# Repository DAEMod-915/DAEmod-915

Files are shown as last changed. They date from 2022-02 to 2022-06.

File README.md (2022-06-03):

# DAEMod-915
Bradley University senior capstone project by Peter Handler, Connor Dickey, and Philip Pierce for a 915MHz ISM open-source and open-hardware digital transceiver implementing Digital radio modes that uses a configurable duty cycle compared to the proprietary alternative LoRa. The goal is to create an example board for digital radio communication. Our design focuses on extensible and easy communication which is configurable to specific use cases like a remote trail camera system or a modernized pager system. We chose low-cost and ubiquitous hardware to build a sustainable platform. Overall, this repository showcases the potential use cases of a finalized product

For more information please read all the existing [documentation](./docs/) about the project.

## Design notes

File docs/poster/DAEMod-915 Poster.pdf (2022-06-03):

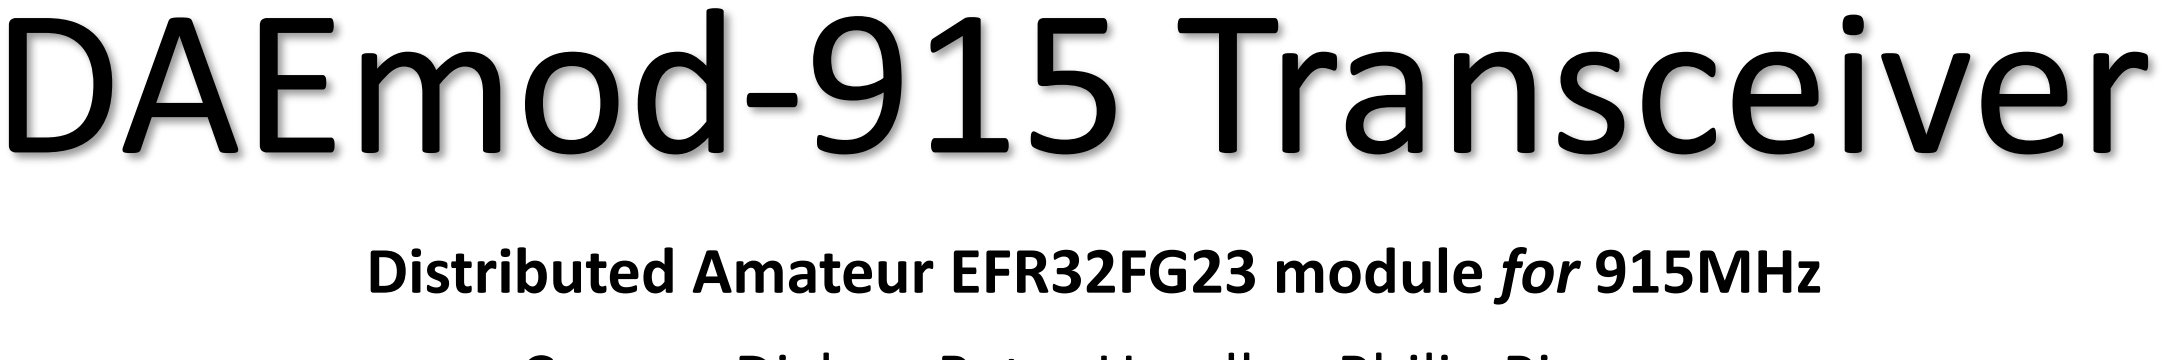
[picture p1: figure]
DAEmod-915 Transceiver

# Distributed Amateur EFR32FG23 module for 915MHz Connor Dickey, Peter Handler, Philip Pierce Advisors: Dr. Prasad Shastry and Dr. Aleksander Malinowski

### Bradley University Department of Electrical and Computer Engineering

# Goals

We are creating a 915MHz open-source and open-hardware system for digital radio experimentation in the under-utilized 915MHz ISM band allocation. The main features of the project include a configurable duty cycle and support for multiple FSK/ASK modes. As a result, it is configurable to specific use cases like a remote trail camera or a modernized pager system. We chose low-cost and ubiquitous hardware (ESP32, I2C sensors, EFR32FG23, ...) to build a sustainable platform and showcase the potential use cases of a finalized product. Overall, our design focuses on extensible and easy communication where traditional infrastructure is not suitable.

# Abstract

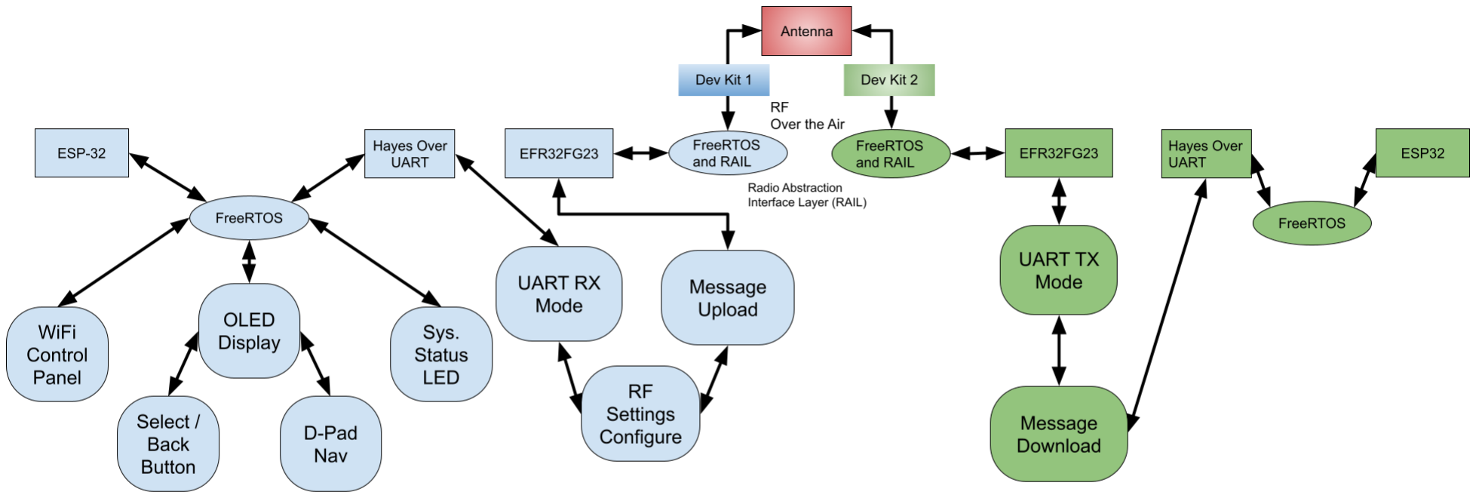
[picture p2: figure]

## ESP32

- Development environment in PlatformIO for VSCode using Espressif 32.
- ESP-PROG for live debugging
- Create set of control signals over UART in the form of AT / Hayes commands.
- Listen on local WiFi server with options to send and print received data.
- GPIO button to start web server, automatically sleep after inactivity.

In the US, the 915MHz band is one of the Industrial, Scientific, and Medical bands that covers a frequency range of 902–928 MHz. Besides LoRa, this band isn't as widely used as 433MHz or 2.4GHz. In the table, we compare our goal product against LoRa

# Background Info

The prototype for the DAEmod-915 is basic PCB design for the development and single board device for use in the DAEmod-915 ecosystem. While the board prototype has not yet gone to production, the board will be produced in a small run to test before the first batch of boards is placed.

# Prototype

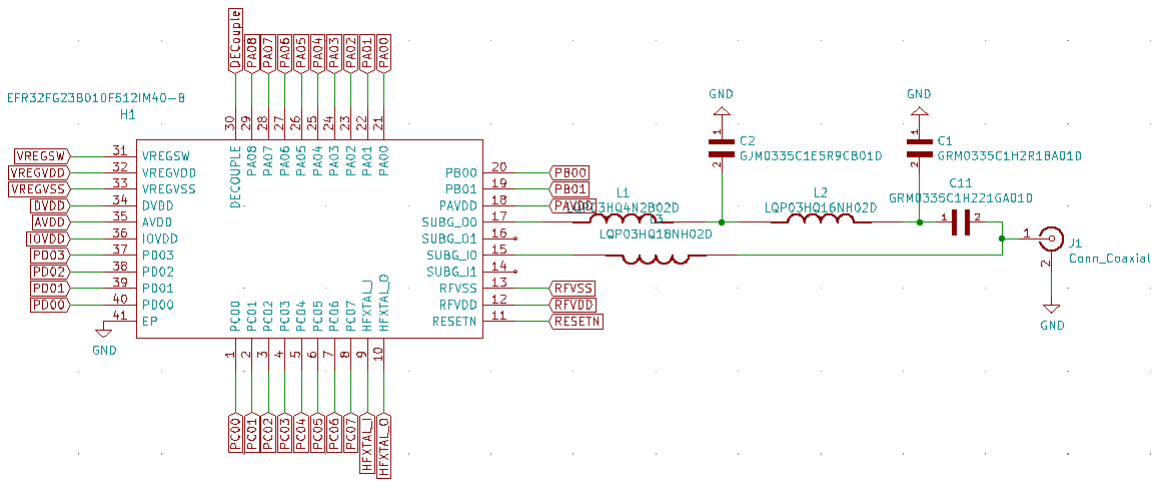
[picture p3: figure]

# Testing Procedures

PCB: The prototype PCB design is at the beginning stages while we wait for parts from the first round grant from the ARDC. The prototype PCB will include mounting locations for the OLED screen, battery connector, GPIO pins, dev kit EFR32FG23, and ESP32 headers. This PCB is a interconnect and tinker board for the project. With room for intergraded modules and future hardware that will be designed for specific products and use cases.

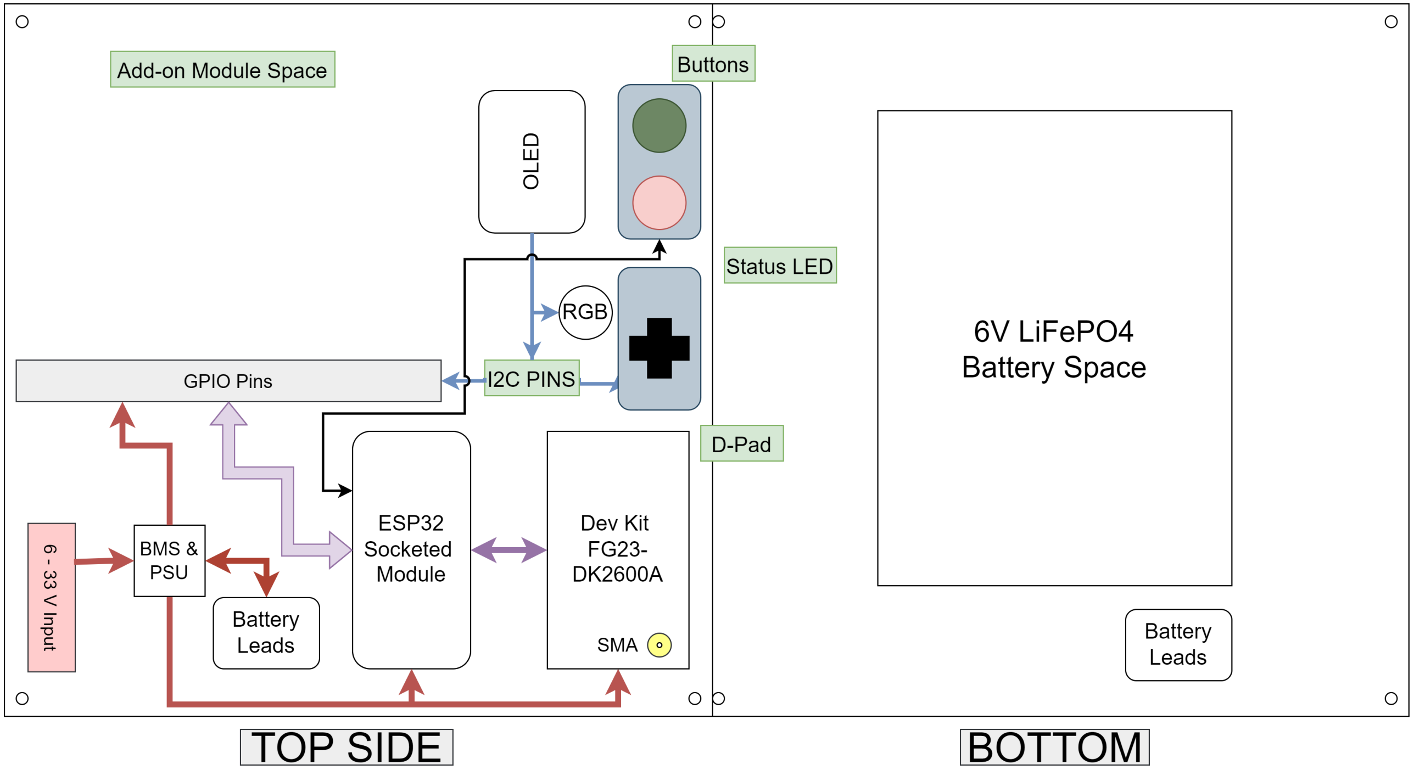
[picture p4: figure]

GitHub: Continued development thought the project GitHub will allow for third-party contributors to continue and expand the software and hardware support. This support will allow for new hardware to be compatible with the current hardware and future hardware. The GitHub will also host documentation for new data modes to be supported by the hardware which can change the use case for the hardware.

Funding: Once the prototype stage of the project is completed, a new grant for a limited production run will be requested from ARDC (Amateur Radio Digital Communications). This grant will allow for development kits for the post-prototype version of the board to be created and seeded for continued development and testing by amateur radio operators and developers.

# Future Development

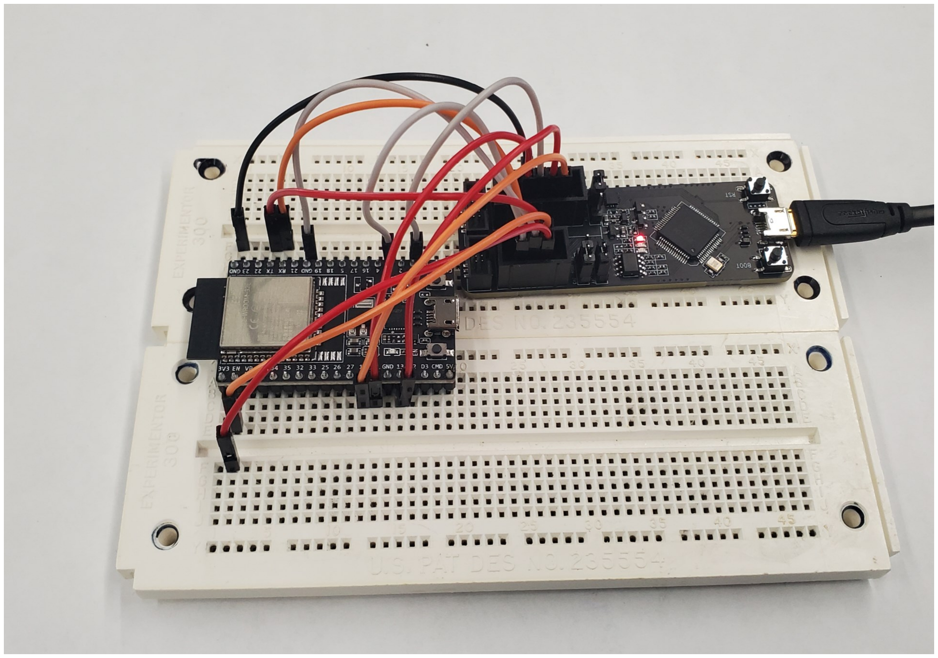
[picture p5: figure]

## Dev Kit FG23-DK2600A

- Development environment in Simplicity Studio
- Low Cost, $40
- Selectable modulation schemes including: FSK, ASK, GFSK, AFSK, GMSK, OOK, OQPSK-DSSS
- Silicon Labs IC for final PCB EFR32FG23A010f256GM48
| LoRa | Our Product
Frequency | 902-928 MHz | 902-928 MHz
Data Rate | 300 bit/s -27 kbit/s | 512 bit/s -400 kbit/s
Duty Cycle | Very Low | Up to 100%
Hand-Shake | Required Handshake | Optional Handshake
Broadcasting | Does not Support | Support
License | $6000 Yearly | GPLv3

The prototype of this project is designed to allow developers and enthusiasts to attach various modules with additional functionality using various Communication I/O Protocols, We are planning to roll out our initial proof-of-concept with Display, GPS, Battery, and Environment Sensors. The display allows users to see system status and information at a glance and the Battery will allow for portable use. Module support will not stop there, as the ability to continue development with future devices is likely with the massive catalog of common products that use UART, SPI, I²
C. As an example, we can imagine advanced sensors like Doppler Radar or Thermal Imaging sensors being useful to examine the state of real world objects without infrastructure.

# Prototype Block Diagram

# Software Design

## •Adhere to open source software and hardware design philosophy •Build a modular and low cost prototype allowing entire community

to contribute.

## •Create highly configurable firmware which is easily modifiable by

community and end users.

Our quantitative testing will be done with the Battery, ESP, Display, RGB LED, and Transceiver.
- Max Range Testing for 2dbi and 5dbi Antenna
- Theoretical 1.80 Miles for 2dbi
- Theoretical 9.3 Miles for 5dbi
- Power Draw on Maximum RF Tx Power
- Power Draw on Minimum RF Tx Power
- Data Rate at max range for different RF Protocols
- Spurious emissions
- Power envelop of signal
- Signal to Noise Ratio

Our function testing outline to validate the proof-of-concept system.
- Component level testing
- Software stability
- Proper hardware connections
- Transceiver Module Operation
- Successful Tx/Rx modulation
- Compliance with regulations
- Module Testing
- Operates as intended
- Communication between systems

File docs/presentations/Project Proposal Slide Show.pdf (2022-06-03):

# 915 MHz Transceiver for Digital Communication

Team: Peter Handler, Philip Pierce, and Connor Dickey
Advisors: Dr. Aleksander Malinowski and Dr. Prasad Shastry Department of Electrical and Computer Engineering, Bradley University

Presentation Outline ● Why this project exists ● Device Specifications ● System Modularity ● Project Timeline ● Additional Considerations ● Conclusion

# Why this project exists

# Project overview

### - Lack of available 915MHz open-source and open-hardware modules - As an example use case and practical implementation of the 915MHz module - Enable extensible and easy communication tailored to more specific use cases

- Low Cost and ubiquitous hardware to facilitate inexpensive modules.

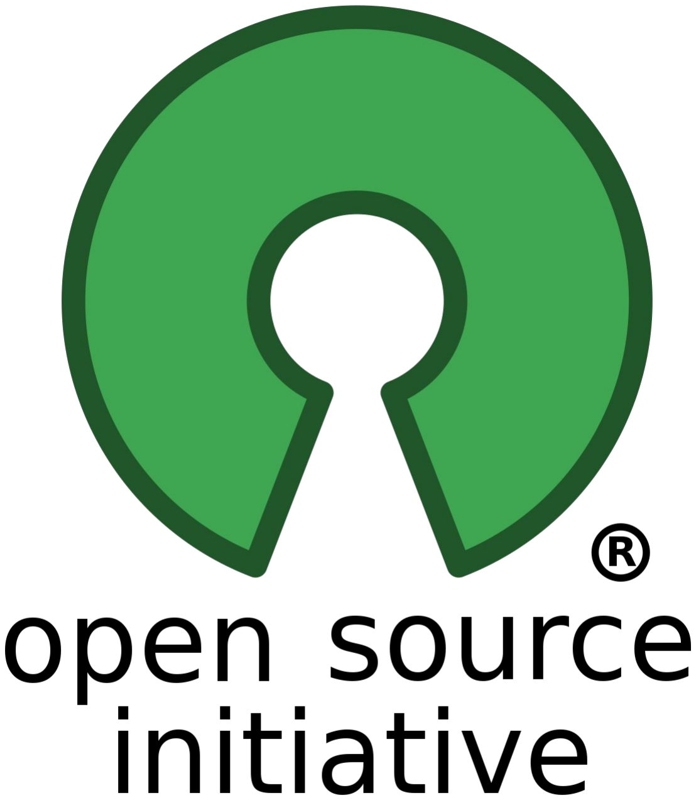
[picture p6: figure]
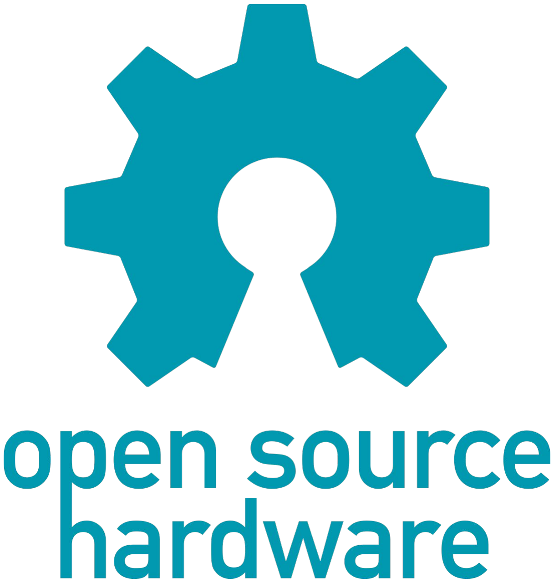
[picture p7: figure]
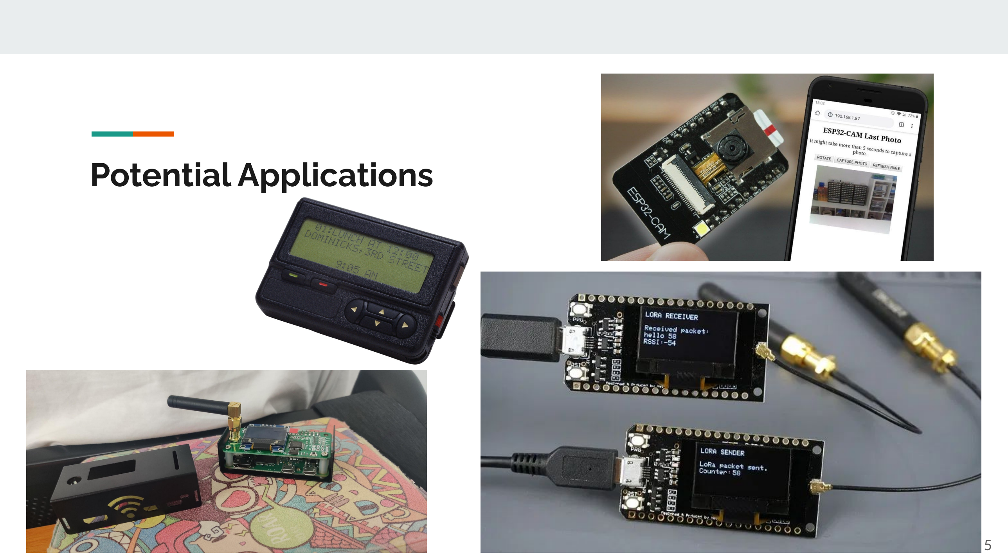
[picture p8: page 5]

# Potential Applications

# Table of LoRa WAN vs our Product

| LoRa | Our Product
Frequency | 902-928 MHz | 902-928 MHz
Data Rate | 300 bit/s - 27 kbit/s | 512 bit/s - 9.6 kbit/s
Duty Cycle | Very Low | Up to 100%
Hand-Shake | Required Handshake | Optional Handshake
Broadcasting | Does not Support | Support
License | $6000 Yearly | Free for use

# Device Specifications

# Preliminary Specifications of Transceiver module

- Theoretical Range
- 2dbi Antenna ideal range is 2.9km (1.80 Miles)
- 5dbi Antenna ideal range is 15km (9.3 Miles)
- Baseline Current draw at 3.3V
- Sleep draw is .8mA
- Full TX draw is 120mA
- RX draw is 20mA
Transceiver | MAX 7037
Modulation | FSK ASK
Antenna | SMA male 50 Ω
Power Max | 10 dBm - 10mW
Frequencies | 915 ISM band (902-928 MHz)

# Preliminary Specifications of Control module

- Baseline Current draw 3.3V
- Sleep draw is .8mA
- RF Tx off draw is 40mA
- RF Tx on draw is 160mA
- RF Tx off, Wifi/BT on draw 240mA
- External power budget 12V
- 1A peak draw to peripheral devices
Microcontroller | ESP 32
Communication I/O Protocols | SPI, I2C, WiFi, BT UART
Power Supply | 12V → 5V → 3.3V
Supported Modules | Camera, Display, GPS, Battery, and Environment Sensor

Function testing | Quantitative Testing
- Component level testing
- Software stability
- Proper hardware installation
- Digital Radio
- Successful Tx/Rx modulation
- Compliance with regulations
- Module Testing
- Operates as intended
- Communication between systems
- Max Range Testing for 2dbi Antenna
- Max Range Testing for 5dbi Antenna
- Power Draw on Maximum RF Tx Power
- Power Draw on Minimum RF Tx Power
- Power Draw for different RF Protocols

B.O.M.

QTY | Vendor | Vendor Part | ITEM DESCRIPTION | UNIT PRICE | TOTAL
1 | Digikey | MAX7037EVKIT915#-ND | Eval Board Max7037 | $254.99 | $254.99
10 | Digikey | MAX7037EGL+-ND | MAX7037 Chips | $5.96 | $59.62
2 | Digikey | 343-ANT-916-CW-RCL-SMA-ND | SMA 900Mhz Hi Gain (Small) Antenna | $8.68 | $17.36
2 | Digikey | 2151-RST-W1B6-10808-22M-FY-001-ND | SMA 900Mhz Low Gain (Small) Antenna | $4.64 | $9.28
2 | Digikey | 1597-104020250-ND | OLED Display 1.12 (SH1107) v3.0 128x128 resolution | $12.50 | $25.00
1 | Digikey | 1597-103020272-ND | I2C HUB (6 PORT) | $1.70 | $1.70
1 | Digikey | 1597-1092-ND | 4PIN MALE JUMPERS 5PACK | $3.20 | $3.20
1 | Digikey | 1597-109020022-ND | GPS module for GPS / Beidou / Glonass / Galileo / QZSS / SBAS | $13.10 | $13.10
2 | Digikey | 1597-1674-ND | Switch Human Interface 5WAY | $4.90 | $9.80
2 | Digikey | 1597-104020169-ND | RGB LED | $4.40 | $8.80
2 | Digikey | 1597-111020103-ND | Switch Human Interface Large Dual Button | $2.40 | $4.80
1 | Digikey | 223-1785-ND | MS8607 SENSOR FOR GROVE SYSTEM | $16.09 | $16.09
2 | Digikey | 1597-1687-ND | ESP32-CAM 2MP WIFI+BT AI-THINKER | $10.00 | $20.00
2 | Digikey | 1965-ESP32-DEVKITC-32E-ND | ESP32-WROOM-32E series Transceiver Evaluation Board | $10.00 | $20.00
1 | Amazon | SMA Female Base | SMA Female Jack Connector 10-Count | $7.89 | $7.89
1 | Amazon | B07BBPX8B8 | UART Cable | $10.99 | $10.99
SUBTOTAL | $482.62
SHIPPING | $12.00
TOTAL | $494.62

# System Modularity

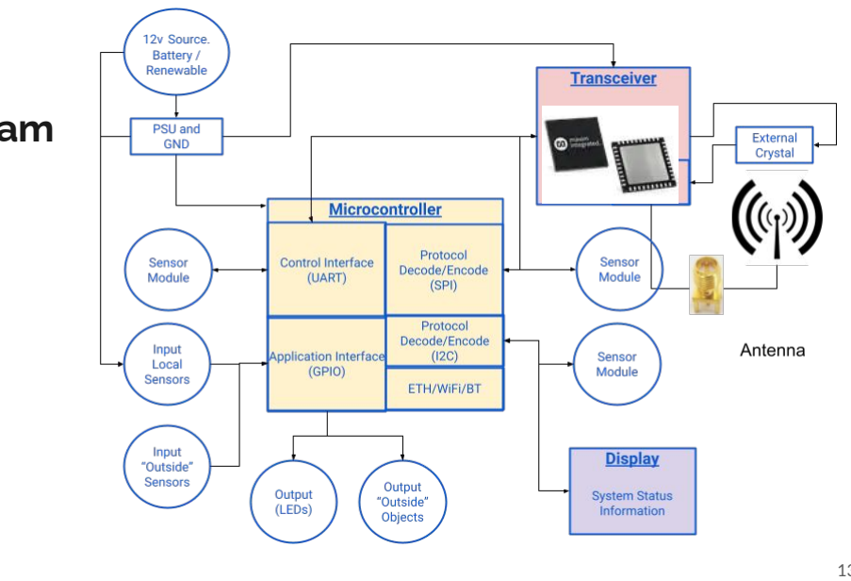
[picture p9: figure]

# Block Diagram

# Potential Modular Accessory

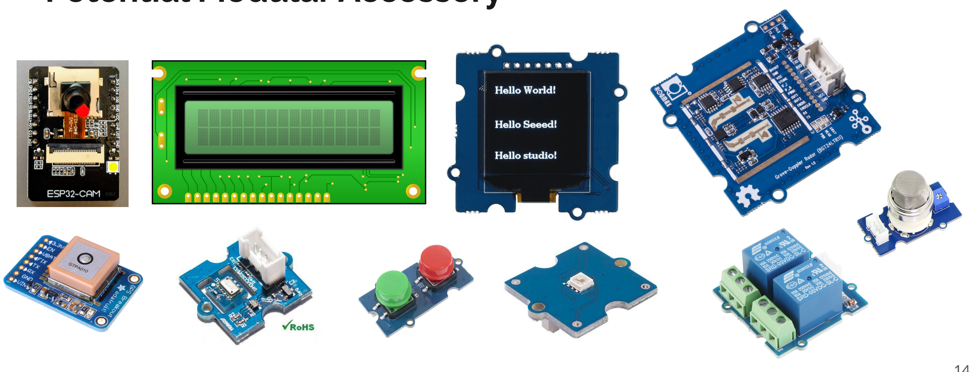
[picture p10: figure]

# Project Timeline

# High Level Timeline Overview

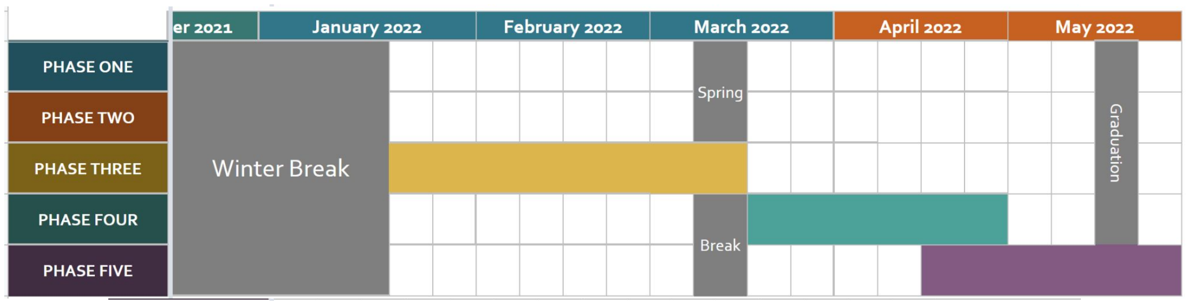
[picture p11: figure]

Senior Project Progress

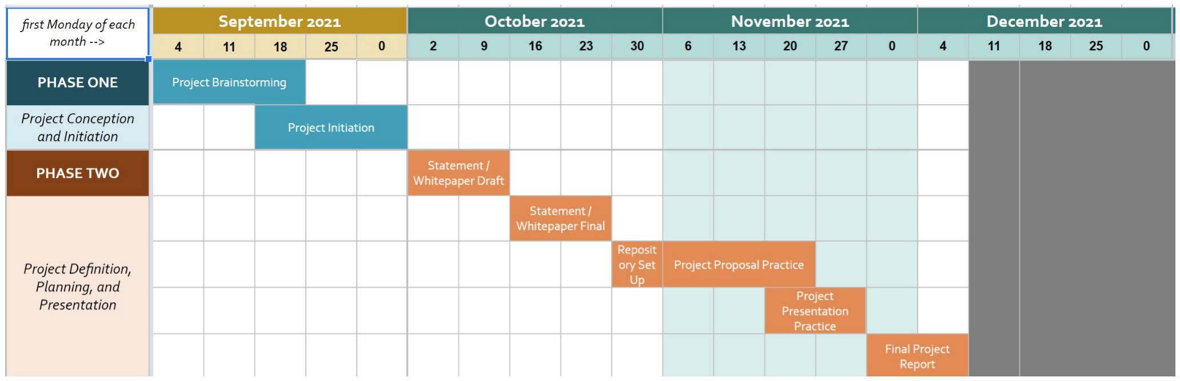
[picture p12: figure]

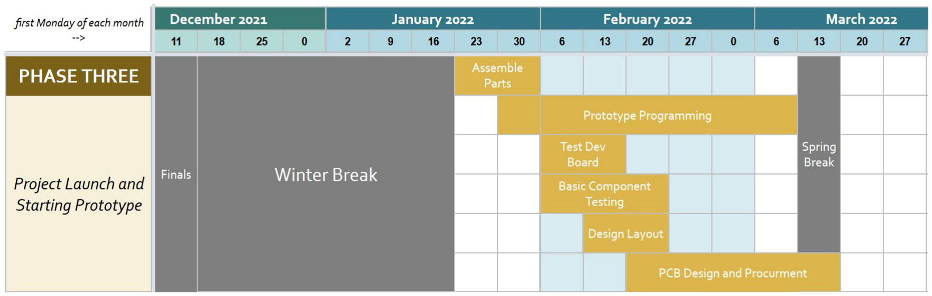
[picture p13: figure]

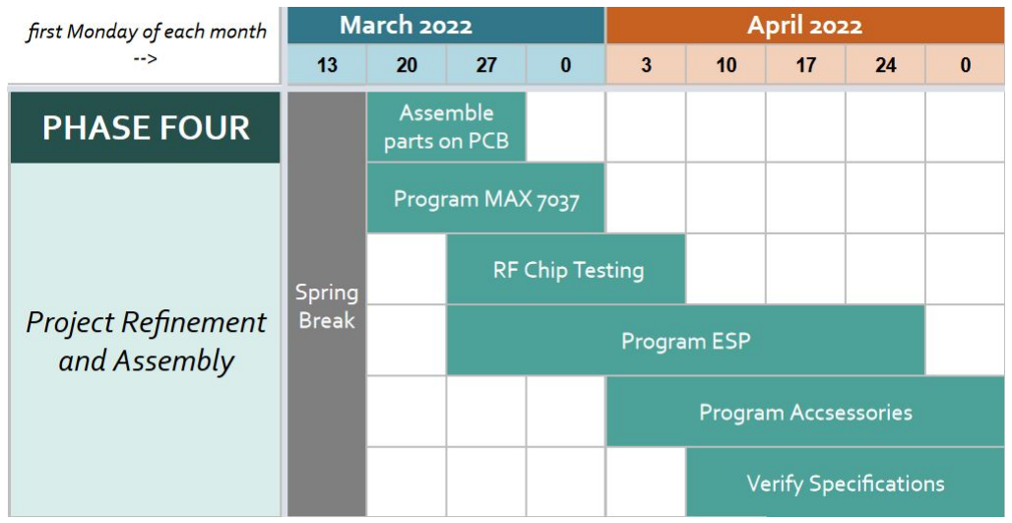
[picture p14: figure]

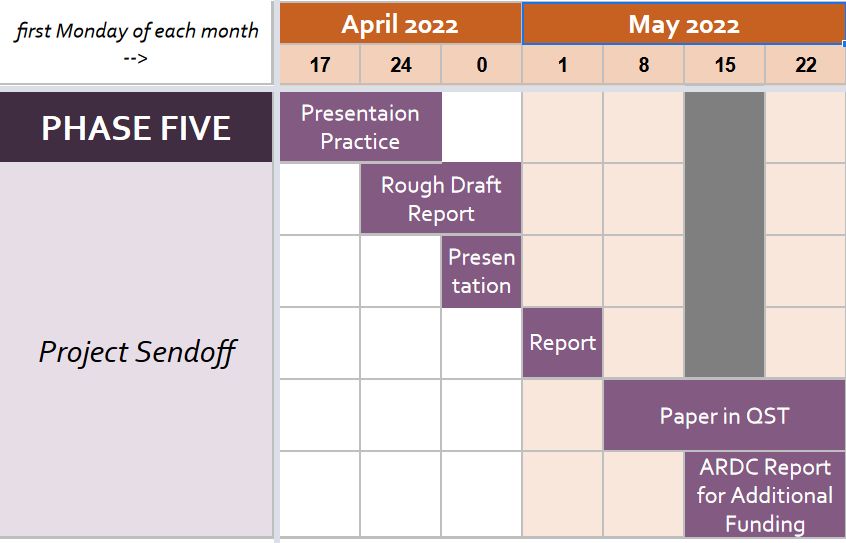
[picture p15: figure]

# Division of Work

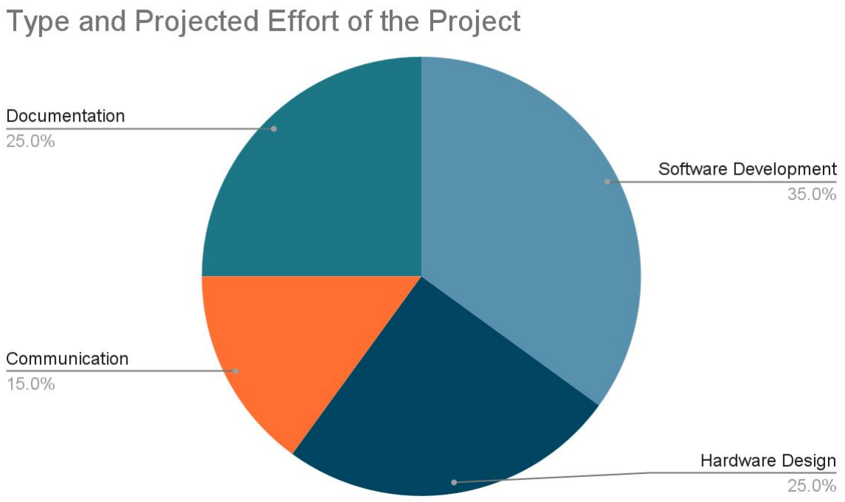
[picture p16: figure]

- Software Development
- Hardware Design
- Communication Schemes
- Documentation
- All have general knowledge in topics

# Parts

Three rounds of funding

1. ECE Department
2. ARDC R&D
3. ARDC Production

# Additional Considerations

Software and Tools ● PCB Designer / CAD ○ -Keysight PathWave ADS ○ -KiCAD ● Embedded Systems Development ○ VS Code + ESP-IDF ESP32 ○ Github ● RF Lab ○ Network Analyzer ○ Spectrum Analyzer ○ Oscilloscope ○ Logic Analyzer

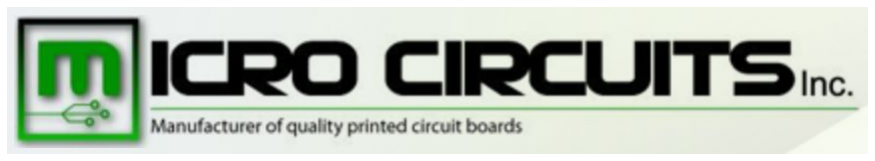
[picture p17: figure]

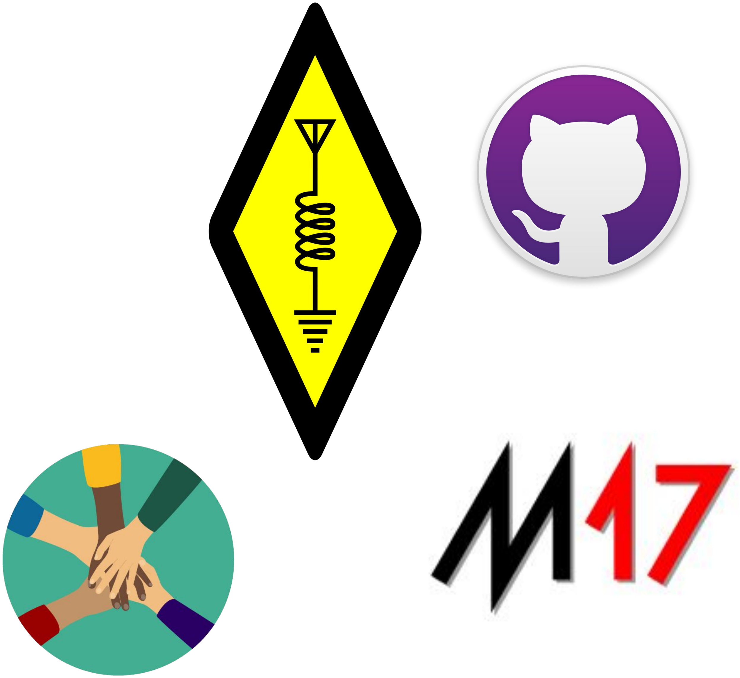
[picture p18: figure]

# Project Future

### - Endless Applications - Driven by Community Engagement - Additional Communication Protocols

# Conclusion

# In Summary

### - Microcontroller powered RF transceiver board for digital radio modes in the

915 MHz ISM band.

### - Will be entirely Open source and Open hardware to make a positive impact in

open initiatives and receive contributions from others.

### - Use a higher duty cycle and be designed with extensibility in mind compared to

the popular and proprietary alternative LoRa.

### - Use ubiquitous and inexpensive hardware to build the board and interface with

a variety of external modules.

# Any Questions?

# References

- https://www.espressif.com/sites/default/files/documentation/esp32_datasheet_en.pdf
- https://datasheets.maximintegrated.com/en/ds/MAX7037.pdf
- https://lora-alliance.org/resource_hub/lorawan-104-specification-package/

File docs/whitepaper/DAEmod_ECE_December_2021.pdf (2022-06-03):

# DAEmod-915: Open-Source Open-Hardware 915MHz Transceiver

Bradley University Senior Capstone Project

Peter Handler
Electrical Engineering
Bradley University
Peoria, IL
phandler@mail.bradley.edu

Philip Pierce
Electrical Engineering
Bradley University
Peoria, IL
ppierce@mail.bradley.edu

Connor Dickey
Electrical Engineering
Bradley University
Peoria, IL
cdickey@mail.bradley.edu

Dr. Aleksander Malinowski
Electrical Engineering Professor Bradley University
Peoria, IL
olekmali@fsmail.bradley.edu

Dr. Prasad Shastry
Electrical Engineering Professor Bradley University
Peoria, IL
snp@fsmail.bradley.edu

CONTENTS

I | Introduction | 3
I-A | Project Overview | | 3
I-B | Main Competition | | 3
I-C | Potential Applications | | 3
II | Preliminary Specifications | 3
II-A | Preliminary Specifications of Transceiver module | | 3
II-B | Preliminary Specifications of Control module | | 3
III | System Modularity | 4
III-A | Block Diagram | | 4
III-B | Potential Modular Accessories | | 4
IV | Bill of Materials | 4
V | Testing | 4
V-A | Quantitative Testing | | 4
VI | Project Timeline | 4
VI-A | Fall 2021 | | 4
VI-B | Spring 2022 | | 4
VI-C | Division of Work | | 4
VII | End-Use Requirements | 5
VIII Additional Considerations | 5
VIII-A Rounds of Funding | | 5
VIII-B Software and Tools | | 5
IX | Conclusion | 5
References | 5
Appendix | 6

Abstract—Within the market, we found a lack of available 915MHz open-source and open-hardware modules for implementing Digital radio modes. To help remedy this deficiency we are creating one such board and module. The board will be an example use case for our digital radio communication and showcase potential use cases for the project.
Index Terms—open source, open hardware, radio, communication, rf, digital, transceiver
I. INTRODUCTION
A. Project Overview
We believe there is a market for a readily available 915MHz open-source and open-hardware system to enable extensible and easy communication that is easily tailored to specific use cases. This proposal outlines the preliminary research, initial specifications, and the steps we are taking to carry out this project. To complete a practical implementation of the 915MHz module within the limited senior project timeline, it will make use of low cost and easy to get hardware to lower the barrier for future contributors. Also, cheap and ubiquitous hardware will allow the final product to be relatively inexpensive.
In the US, the 915MHz band is one of the Industrial, Scientific, and Medical bands that covers a frequency range of 902–928 MHz. Besides outdated systems and LoRa, this band isn’t as widely used as 433MHz or 2.4GHz. As a result, the 915MHz band is a mostly underpopulated service for most devices today. This frequency range strikes a good balance between range, power, and available spectrum for our intended application.
B. Main Competition
As mentioned, the main competitor in this space is LoRa, a proprietary standard for mesh networks. This also means there are a variety of popular 915MHz ISM boards available. The standout difference is our protocol implementation that will allow for a high duty cycle. In Table I below, we highlight the main differences between LoRa and our project.
Spec | LoRa | Our Project
Frequency | 902-928 MHz | 902-928 MHz
Data Rate | 300 bit/s - 27 kbit/s | 512 bit/s - 400 kbit/s
Duty Cycle | Very Low | Up to 100%
Hand-Shake | Required Handshake | Optional Handshake
Broadcasting | Does not Support | Support
Licensing | $6000 Yearly | GPLv3

TABLE I: LoRa vs. Our Project

Overall, our board would be a good alternative for the use cases where a consistent data rate is wanted, if one direction broadcast qualities are required, or using amateur radio privileges.

C. Potential Applications
Potential applications of an open 915MHz transceiver include large data transmissions, one-way transmissions, and amateur radio communication. A large data transmission example is that of a remote trail cam. However, the product is not too applicable where strong infrastructure exists. Therefore, this is best applied when a outside the range of WiFi and free from the cost of cellular. One example of one-way transmission could be a modernized pager system where large and complex messages can be broadcast. This could be the other way around for sensors that do not need to receive commands and instead just regularly transmit information to a central system. We are expecting this to be used within the amateur radio community as a highly configurable and higher power 33cm digital transceiver. With a successful open source project comes a community around to offer additional support and ideas to further the potential applications.

II. PRELIMINARY SPECIFICATIONS

A. Preliminary Specifications of Transceiver module
After selecting 915MHz as the target frequency, we looked at some various different transceiver ICs that were modern, available, and feature rich. We ended up choosing the Silicon Labs EFR32FG23 transceiver for it’s low cost and ample documentation. Table II list various specifications and limitations that this transceiver includes.
Transceiver | SiLabs EFR32FG23
Modulation | FSK, ASK, GFSK, AFSK, GMSK, OOK, OQPSK-DSSS
Antenna | SMA male 50 Ω
Expected Power | 10 dBm - 10mW
Frequencies | 915 ISM Band (902-928 MHz)

TABLE II: Transceiver Module

Theoretical Range

Pr
Pt

= DtDr

λ

4πd2
(1)

– 2dbi Antenna theoretical range is 2.9km (1.80 Miles) – 5dbi Antenna theoretical range is 15km (9.3 Miles) Baseline Current draw at 3.3V
– Sleep draw is 1.5nA
– Full TX draw is 120mA
– RX draw is 20mA
B. Preliminary Specifications of Control module
While looking at various microcontrollers, we finally selected the ESP32 microcontroller due to the ubiquity of the hardware and cost.
Baseline Current draw 3.3V
– Sleep draw is .8mA
Microcontroller | ESP 32
Communication I/O Pro-tocols | SPI, I2C, WiFi, BT UART
Power Supply | DC Input 6v - 35V and/or BMS 6V LiFePO4
Supported Modules | Camera, Display, GPS, Battery, and Environment Sensor

TABLE III: Control Module

– RF Tx off draw is 40mA
– RF Tx on draw is 160mA
– RF Tx off, Wifi/BT on draw 240mA External power budget 6V
– 1A peak draw to peripheral devices

III. SYSTEM MODULARITY

A. Block Diagram
The prototype of this project is designed to allow developers and enthusiasts to attach various modules with additional functionality. As shown in Appendix A, our design is exposing or making use of SPI, I²C, UART, Wi-Fi, Bluetooth, and GPIO. This design allows for multiple different accessories to be compatible at a time. In Table IV, a summary of the interfaces and planned purposes are outlined.
BMS | Handle DC - DC conversion, LiFePO4 charging, and supply of the main 5V
SPI | Transceiver, Camera
2C I | Environment Sensors, Status Display and control
UART | External Sensors, GPS, Debug Message Output
GPIO | Indicators, Buttons, Control lines

TABLE IV: Inputs and Outputs

B. Potential Modular Accessories
Using various Communication I/O Protocols, there is the potential for many kinds of modules that can extend the usability of the basic transceiver. We are planning to roll out our initial proof-of-concept with Camera, Display, GPS, Battery, and Environment Sensors. The Display allows users to see system status and information at a glance and the Battery will allow for portable use. Module support will not stop there, as the ability to continue development with future devices is likely with the massive catalog of common products that use UART, SPI, I²C. As an example, We can imagine advanced sensors like Doppler Radar or Thermal Imaging sensors being useful to examine the state of real world objects without infrastructure.

IV. BILL OF MATERIALS
Attached in Appendix B is the Full Bill of Materials for the items that we requested from the Bradley University Department of Electrical and Computer Engineering. Future materials and subsequent funds will be needed for a complete prototype system with multiple boards. Considerations and parts selections are currently being made
V. TESTING
Our function testing outline to validate the proof-of-concept system.
- Component level testing
– Software stability
– Proper hardware installation
- Transceiver Module
– Successful Tx/Rx modulation

– Compliance with regulations
- Module Testing
– Operates as intended
– Communication between systems
A. Quantitative Testing

Quantitative testing will be done with the Battery, ESP, Display, RGB LED, and Transceiver. Equipment used to do the following tests will include calibrated DMMs, Spectrum Analyzers, and Oscilloscopes.

- Max Range Testing for 2dbi Antenna
- Max Range Testing for 5dbi Antenna
- Power Draw on Maximum RF Tx Power
- Power Draw on Minimum RF Tx Power
- Power Draw for different RF Protocols
- Spurious emissions
- Power envelop of signal
- Signal to Noise Ratio

VI. PROJECT TIMELINE

A. Fall 2021

The first phase of the project involved brainstorming and defining the scope of the project. The next phase is creating the presentation and proposal documents that outline our goals, plans, and specifications. Currently, we are at this stage of the project, having recently given our project presentation to students and faculty. See the attached graphical timeline for more details in Appendix C.

B. Spring 2022

Starting in 2022, the parts will arrive, proof-of-concept building and programming begins, and the prototype PCB gets designed. In phase four, the finalized PCB will arrive, the system is tested against our requirements, and major programming is completed. The final phase of the project sets up its future as we finish documentation and report on the project outcome. See the attached graphical timeline for more details in Appendix D.

C. Division of Work

Tasks listed above are grouped into 4 different topics and dispersed as follows:

- Software
- Hardware Design
- Communication Protocols
- Documentation

Shown in Figure 1 the work of the various tasks are equal in size and each team member has basic knowledge on those topics.

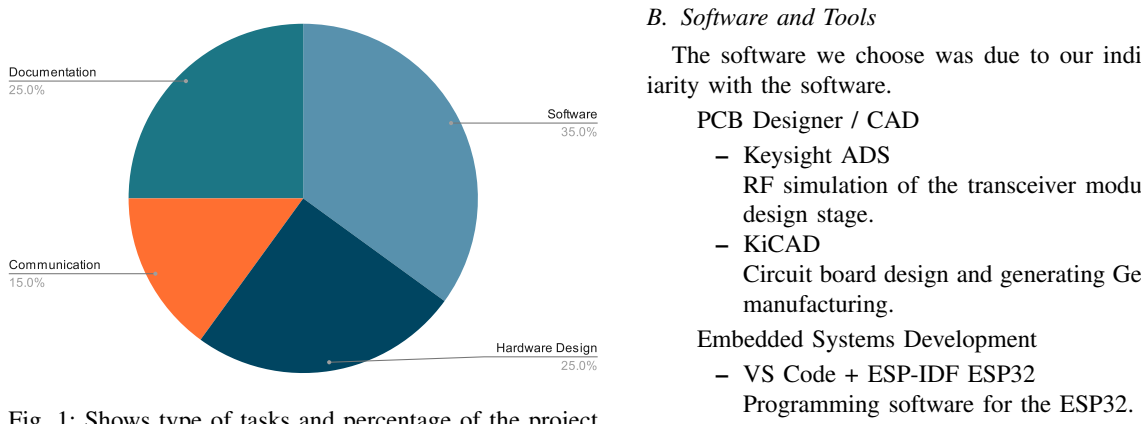
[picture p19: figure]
B. Software and Tools; iarity with the software.; PCB Designer / CAD; – Keysight ADS; design stage. – KiCAD; manufacturing.; Embedded Systems Development; – VS Code + ESP-IDF ESP32 Programming software for the ESP32.

Fig. 1: Shows type of tasks and percentage of the project

VII. END-USE REQUIREMENTS

Public Health, Safety, and Welfare:
RF Exposure (minimal radiated power in non-ionizing radiation) and a proper part Part 15 and Part 97 Exposure will be conducted. Service-life of the entire board with be tested and documented.
Global:
Open Source and Open Hardware licensing allow anyone to contribute. As well implement the board in their projects. Environmental:
Open Hardware allows for ease of modification for the user to reuse hardware after the end of service life.
Business:
Open Source and Open Hardware allow free production and modification with a license to be determined in case we need a passive developmental fund for continued improvement and upkeep of active project maintainers.
Economic Factors:
Low Cost and ubiquitous hardware to facilitate inexpensive modules.
Testing:
Testing will guaranty the module works in a minimum viable product to be implemented.

VIII. ADDITIONAL CONSIDERATIONS

A. Rounds of Funding

Currently, the project has received limited funds by the Bradley University Department of Electrical Engineering for limited proof-of-concept.
Additional funding sought from ARDC would be used to further development with initial prototypes.
A third round of funding will be sought from the Amateur Radio Digital Communications Foundation (ARDC),to produce a production run of board to create development kits that will be seeds to the community and encourage growth of the product.

The software we choose was due to our individual famil-

RF simulation of the transceiver module during the

Circuit board design and generating Gerber Files for

– Github
Maintaining the project files and allowing for collaboration.
Tools
– Network Analyzer
– Spectrum Analyzer
– Oscilloscope
– Logic Analyzer
– Digital Multi-meter

IX. CONCLUSION
Our microcontroller powered RF transceiver board for digital radio modes will operate in the 915 MHz ISM band. This project will be entirely Open-Source and Open-Hardware to make a positive impact in open initiatives and receive contributions from others. To differentiate we will use a higher duty cycle and be designed with extensibility in mind compared to the popular and proprietary alternative LoRa. To be economical, we will use ubiquitous and inexpensive hardware to build the board and interface with a variety of external modules. We will enable tailoring to more specific use cases, like a one-way pager.

REFERENCES

[1] M. Luis and J. Petruno, “LoRaWAN Certification Protocol Specification,” p. 20. 1955.
[2] “FG23-DK600A | efr32fg23 | 868-915 | mhz | +14 | dbm | Dev
Kit | - | Silicon | Labs,” | FG23-DK600A | EFR32FG23 | 868-915
MHz | +14 | dBm | Dev | Kit | - | Silicon | Labs, | 18-Oct-2021.
[Online]. | Available: | https://www.silabs.com/development-
tools/wireless/proprietary/efr32fg23-868-915-mhz-14-dbm-devkitmanuals. [Accessed: 14-Feb-2022].
[3] “esp32 datasheet en” | espressif. | [Online]. | Available:
https://www.espressif.com/sites/default/files/documentation/esp32 datasheet en.pdf

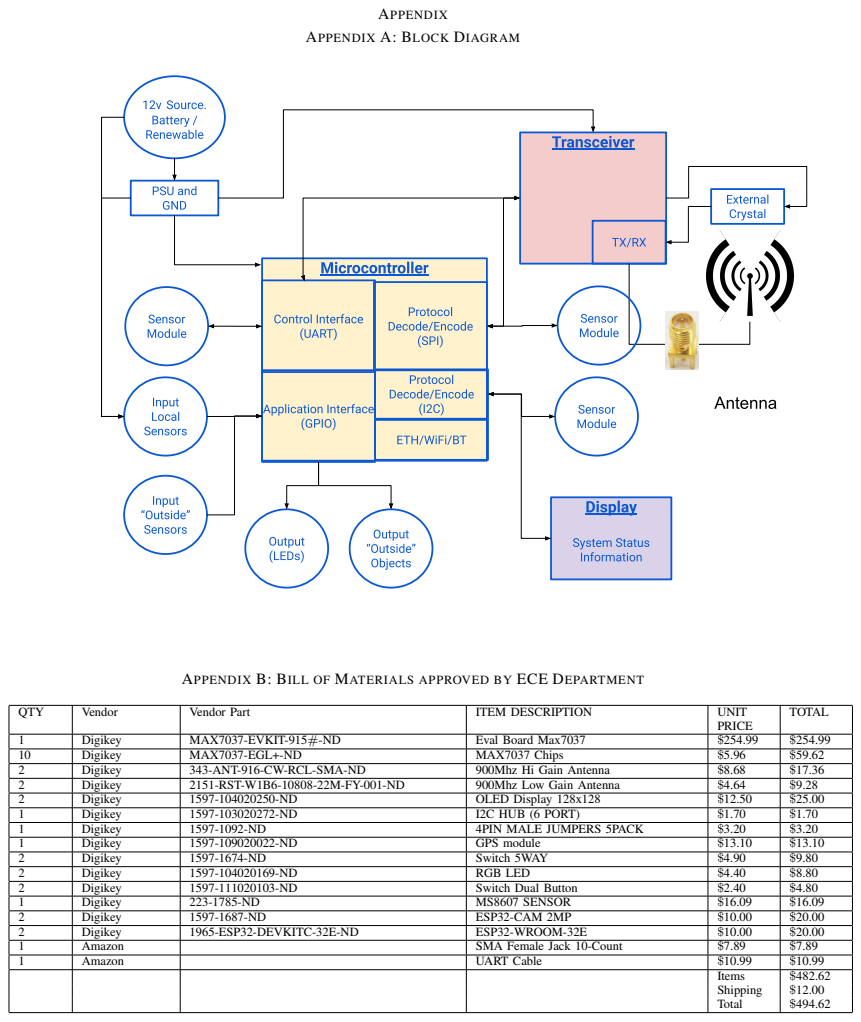
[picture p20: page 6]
APPENDIX

APPENDIX A: BLOCK DIAGRAM

APPENDIX B: BILL OF MATERIALS APPROVED BY ECE DEPARTMENT

QTY | Vendor | Vendor Part | ITEM DESCRIPTION | UNIT PRICE | TOTAL

1 | Digikey | MAX7037-EVKIT-915#-ND | Eval Board Max7037 | $254.99 | $254.99
10 | Digikey | MAX7037-EGL+-ND | MAX7037 Chips | $5.96 | $59.62
2 | Digikey | 343-ANT-916-CW-RCL-SMA-ND | 900Mhz Hi Gain Antenna | $8.68 | $17.36
2 | Digikey | 2151-RST-W1B6-10808-22M-FY-001-ND | 900Mhz Low Gain Antenna | $4.64 | $9.28
2 | Digikey | 1597-104020250-ND | OLED Display 128x128 | $12.50 | $25.00
1 | Digikey | 1597-103020272-ND | I2C HUB (6 PORT) | $1.70 | $1.70
1 | Digikey | 1597-1092-ND | 4PIN MALE JUMPERS 5PACK | $3.20 | $3.20
1 | Digikey | 1597-109020022-ND | GPS module | $13.10 | $13.10
2 | Digikey | 1597-1674-ND | Switch 5WAY | $4.90 | $9.80
2 | Digikey | 1597-104020169-ND | RGB LED | $4.40 | $8.80
2 | Digikey | 1597-111020103-ND | Switch Dual Button | $2.40 | $4.80
1 | Digikey | 223-1785-ND | MS8607 SENSOR | $16.09 | $16.09
2 | Digikey | 1597-1687-ND | ESP32-CAM 2MP | $10.00 | $20.00
2 | Digikey | 1965-ESP32-DEVKITC-32E-ND | ESP32-WROOM-32E | $10.00 | $20.00
1 | Amazon | | SMA Female Jack 10-Count | $7.89 | $7.89
1 | Amazon | | UART Cable | $10.99 | $10.99

Items Shipping Total | $482.62 $12.00 $494.62

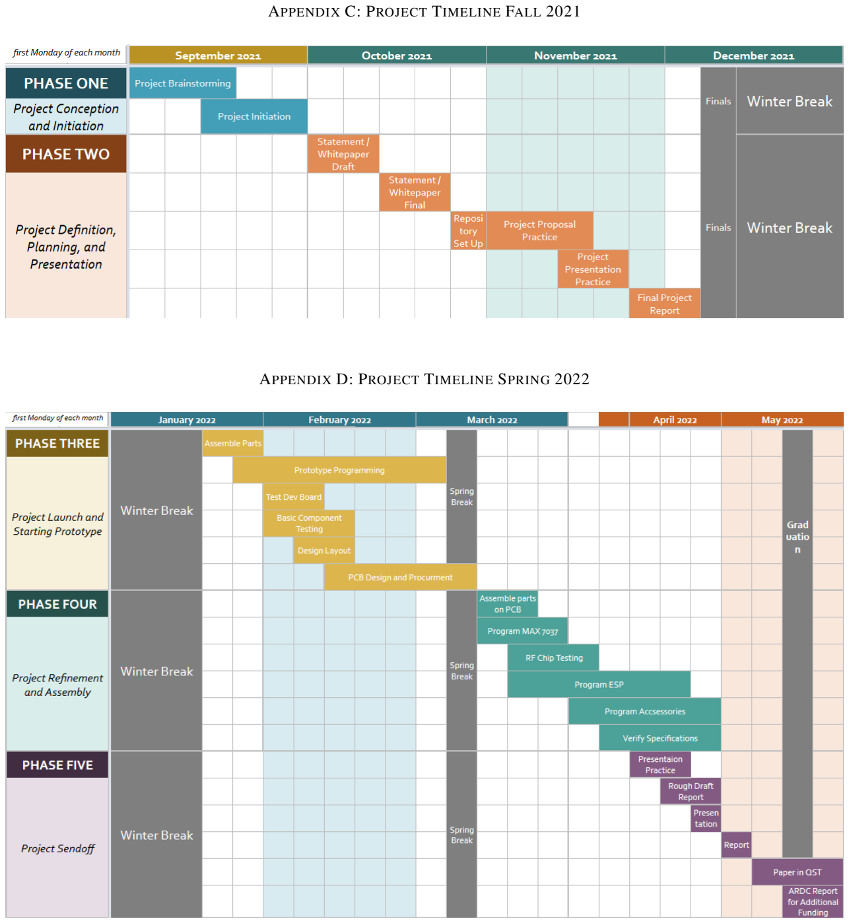
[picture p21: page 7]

APPENDIX C: PROJECT TIMELINE FALL 2021

APPENDIX D: PROJECT TIMELINE SPRING 2022

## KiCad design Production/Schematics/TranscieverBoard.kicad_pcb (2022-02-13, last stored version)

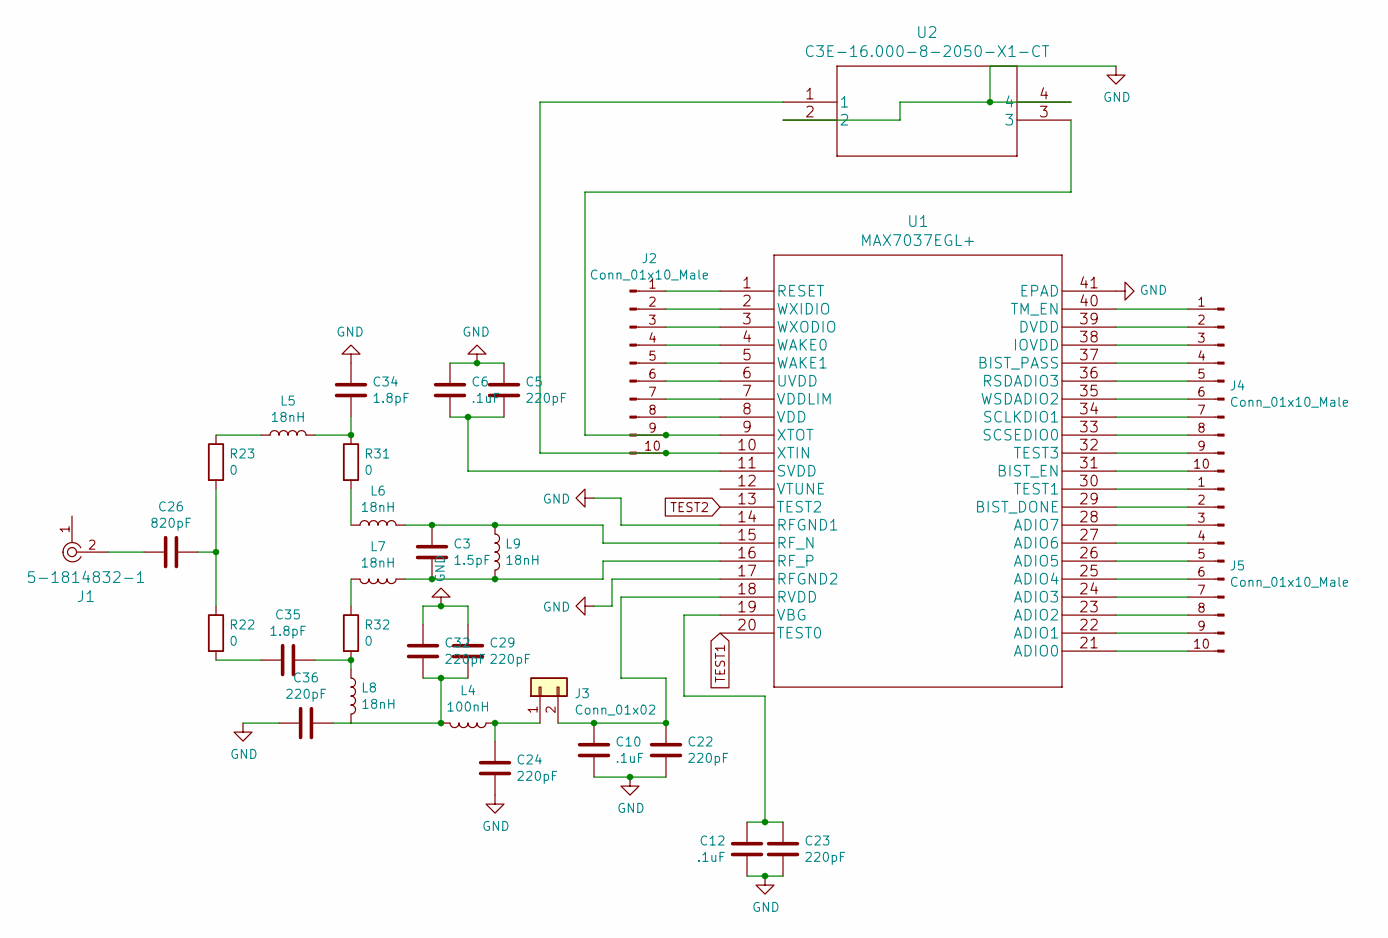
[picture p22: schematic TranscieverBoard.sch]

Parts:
C3: 1.5pF; C_0402_1005Metric
C5, C22, C23, C24, C29, C32, C36: 220pF; C_0402_1005Metric
C6, C10, C12: .1uF; C_0603_1608Metric
C26: 820pF; C_0603_1608Metric
C34, C35: 1.8pF; C_0402_1005Metric
J1: 5-1814832-1; RF_SMA_Vertical_5-1814832-1; MPN 5-1814832-1; Digi-Key_PN A97594-ND
J2, J4, J5: Conn_01x10_Male; PinHeader_1x10_P2.54mm_Vertical
J3: Conn_01x02; PinHeader_1x02_P2.54mm_Vertical
L4: 100nH; L_0402_1005Metric
L5, L6, L7, L8, L9: 18nH; L_0402_1005Metric
R22, R23, R31, R32: 0; R_0402_1005Metric
U1: MAX7037EGL+; MAX7037EGL&plus_
U2: C3E-16.000-8-2050-X1-CT

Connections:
GND: C5.1, C6.1, C10.2, C12.2, C22.2, C23.2, C24.2, C29.1, C32.1, C34.2, C36.2, U1.14 (RFGND1), U1.17 (RFGND2), U1.41 (EPAD), U2.2, U2.4
unnamed: C3.1, L6.2, L9.1, U1.15 (RF_N)
unnamed: C3.2, L7.1, L9.2, U1.16 (RF_P)
unnamed: C5.2, C6.2, U1.11 (SVDD)
unnamed: C10.1, C22.1, J3.2, U1.18 (RVDD)
unnamed: C12.1, C23.1, U1.19 (VBG)
unnamed: C24.1, J3.1, L4.1
unnamed: C26.1, R22.1, R23.2
unnamed: C26.2, J1.2
unnamed: C29.2, C32.2, C36.1, L4.2, L8.2
unnamed: C34.1, L5.2, R31.1
unnamed: C35.1, L8.1, R32.2
unnamed: C35.2, R22.2
unnamed: J2.1, U1.1 (RESET)
unnamed: J2.2, U1.2 (WXIDIO)
unnamed: J2.3, U1.3 (WXODIO)
unnamed: J2.4, U1.4 (WAKE0)
unnamed: J2.5, U1.5 (WAKE1)
unnamed: J2.6, U1.6 (UVDD)
unnamed: J2.7, U1.7 (VDDLIM)
unnamed: J2.8, U1.8 (VDD)
unnamed: J2.9, U1.9 (XTOT), U2.3
unnamed: J2.10, U1.10 (XTIN), U2.1
unnamed: J4.1, U1.40 (TM_EN)
unnamed: J4.2, U1.39 (DVDD)
unnamed: J4.3, U1.38 (IOVDD)
unnamed: J4.4, U1.37 (BIST_PASS)
unnamed: J4.5, U1.36 (RSDADIO3)
unnamed: J4.6, U1.35 (WSDADIO2)
unnamed: J4.7, U1.34 (SCLKDIO1)
unnamed: J4.8, U1.33 (SCSEDIO0)
unnamed: J4.9, U1.32 (TEST3)
unnamed: J4.10, U1.31 (BIST_EN)
unnamed: J5.1, U1.30 (TEST1)
unnamed: J5.2, U1.29 (BIST_DONE)
unnamed: J5.3, U1.28 (ADIO7)
unnamed: J5.4, U1.27 (ADIO6)
unnamed: J5.5, U1.26 (ADIO5)
unnamed: J5.6, U1.25 (ADIO4)
unnamed: J5.7, U1.24 (ADIO3)
unnamed: J5.8, U1.23 (ADIO2)
unnamed: J5.9, U1.22 (ADIO1)
unnamed: J5.10, U1.21 (ADIO0)
unnamed: L5.1, R23.1
unnamed: L6.1, R31.2
unnamed: L7.2, R32.1
TEST1: U1.20 (TEST0)
TEST2: U1.13 (TEST2)

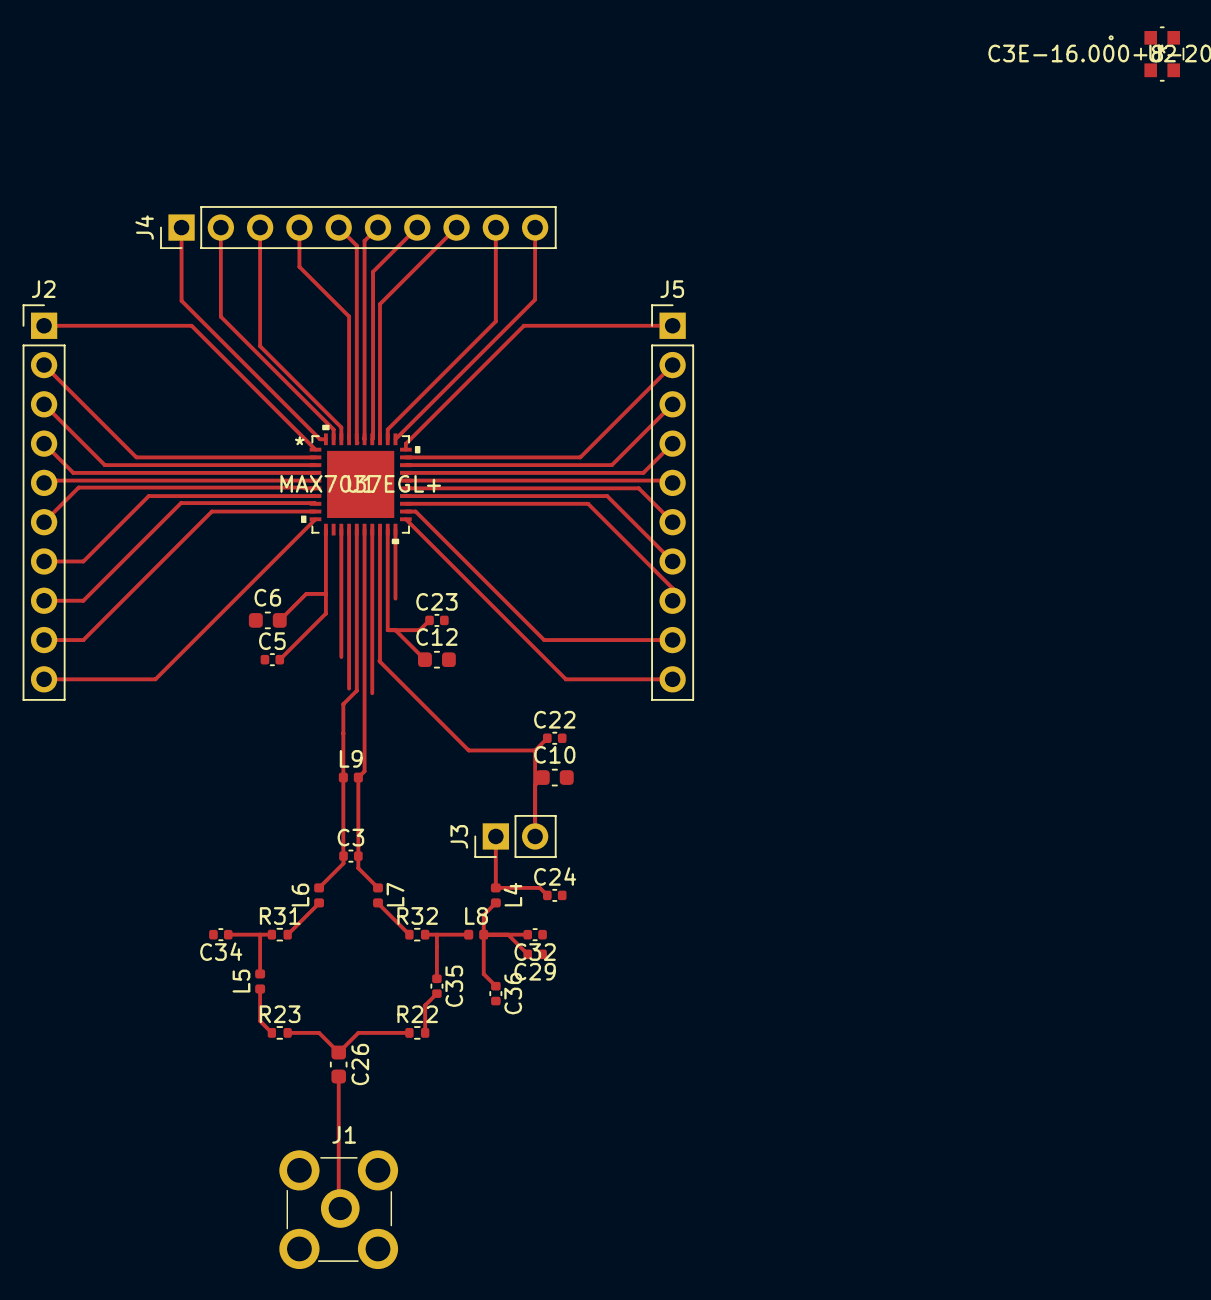
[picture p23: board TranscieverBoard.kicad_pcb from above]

Board: 2 copper layers, 31 parts (0 on the bottom side), 46 nets.

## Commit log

2022-02-02 Addition of MAX7037 Design Files
    Added MAX7037 KiCad Files
    Added /Production
    Added /Production/Schematics
    Added /Production/Parts_Library
    [TranscieverBoard.kicad_pcb, TranscieverBoard.sch, familylist_refdes.csv]
2022-02-13 Gerber Files Generated
    Gerber Files for transceiver module PCB generated
    [TranscieverBoard-B_Cu.gbr, TranscieverBoard-B_Mask.gbr, TranscieverBoard-B_Paste.gbr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]
2022-02-13 Updated PCB
    Updated PCB from MCX to SMA
    [TranscieverBoard.kicad_pcb, TranscieverBoard.sch]
2022-02-13 PCB Design update
    PCB schematic update
    [TranscieverBoard.kicad_pcb, TranscieverBoard.sch]
2022-05-15 Removal of legacy files
    [TranscieverBoard-B_Cu.gbr, TranscieverBoard-B_Mask.gbr, TranscieverBoard-B_Paste.gbr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]
2022-06-03 Spring Semester Presentation with multiple formats.
2022-06-03 Revert README Deletion and added Location for Reading Materials
2022-06-03 Add ESP32 submodule.

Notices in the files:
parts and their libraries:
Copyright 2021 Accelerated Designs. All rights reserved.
